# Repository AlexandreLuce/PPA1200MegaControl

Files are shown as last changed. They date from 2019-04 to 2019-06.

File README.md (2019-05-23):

# PPA1200MegaControl
Hardware and Software based on arduino mega and Nextion lcd touchscreen designed to replace defective Stage Accompany PPA 1200 Front Panel

## This is a Work In Progress !!

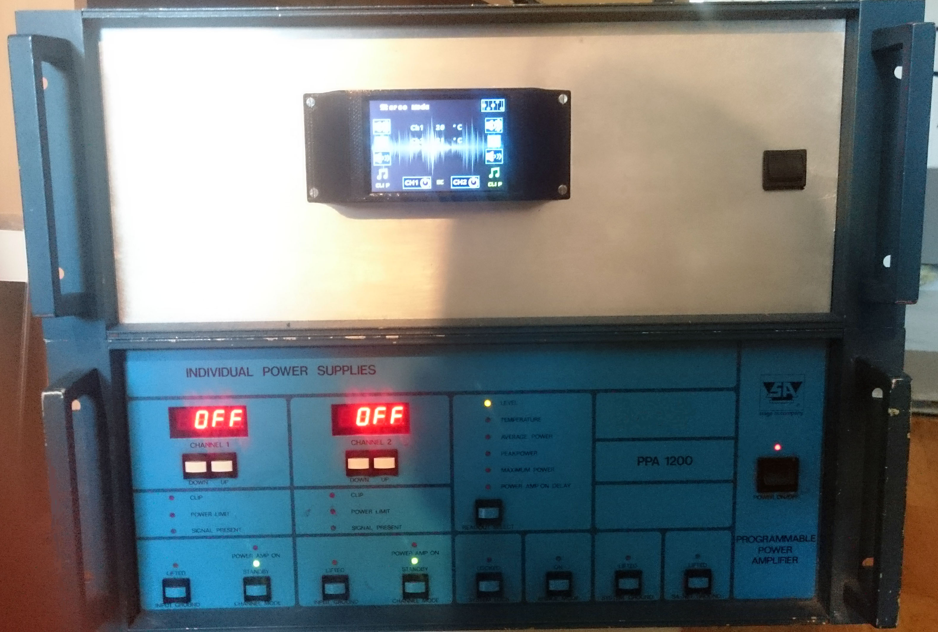
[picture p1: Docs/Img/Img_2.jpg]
Before / After
   

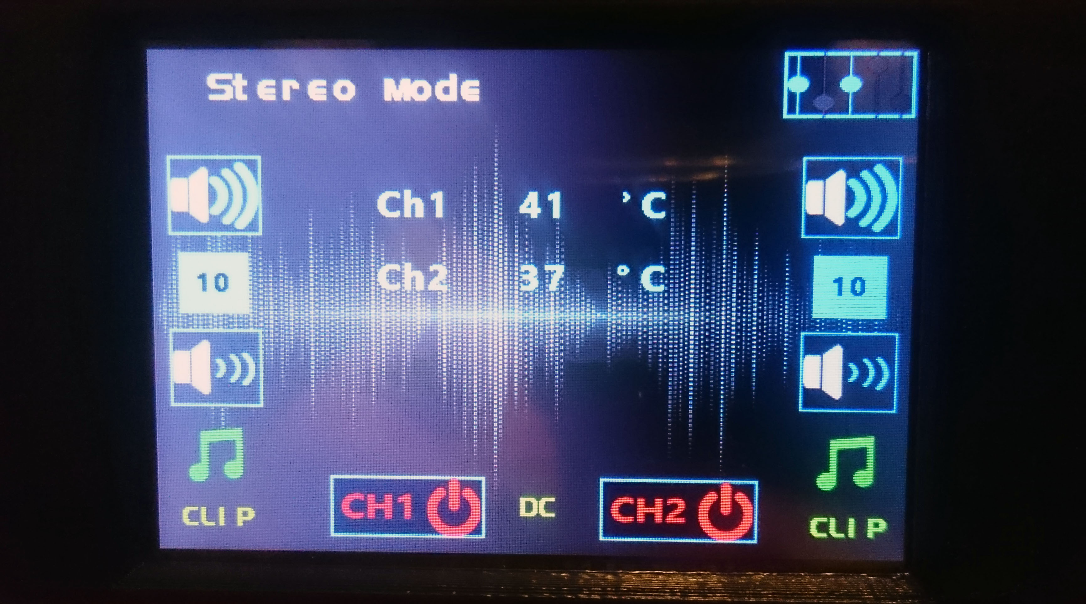
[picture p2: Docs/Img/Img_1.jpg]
Screen


<h2>To Do</h2> 

  - [X] Power off on DC fail function
  - [X] Limit Fan threshold
  - [X] Delay for channel start
  - [X] Test clip feedback
  - [ ] Implement fast ADC
  - [ ] Implement fast digital write
  - [ ] Improve volume function in bridge mode (sync com with AD7545)
  - [X] Fix volume function => Start/Steps
  - [ ] Record Uptime
  - [X] Auto Start Function
  - [X] Arduino feedback to lcd for Lift Chassis, Volume Synchronisation
  - [X] Arduino feedback to lcd for Lift Input and Filter Channels 1 2
  - [ ] Improve 3d part with a sliding cover, and better lcd panel fixing 
  - [X] Find analog input voltage to peak and rms volts conversion
  - [X] Display peak power and rms power
  - [X] Volume reduction function regarding power
  - [X] Volume reduction function in case of clip
  - [ ] Add remote control with RS232 Serial TTL to TCP/ IP RJ45 Convert Transmission Module

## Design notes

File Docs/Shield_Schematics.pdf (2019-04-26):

Vin
+5V | Bus 0 ========= | 1 | 26 | =========Bus 1
GND | Bus 2 ========= | 2 | 25 | =========Bus 3
A0 ================ | Bus 4 ========= | 3 | 24 | =========Bus 5
A1 ================ | Bus 6 ========= | 4 | 23 | =========Bus 7
A2 ================== | Bus 8 ========= | 5 | 22 | =========Bus 9
A3======================= | Bus 10 ========= | 6 | 21 | =========Bus 11
A4==================== | | 7 | 20 | =========RMS V
A5 ================== | Supply Lvl ========= | 8 | 19 | =========RMS I
A6 ================= | CS_AD7545 ========= | 9 | 18 | =========Signal
A7 ================== | Temp ========= | 10 | 17 | =========DC
A8 =================== | Clip ========= | 11 | 16 | =========Peak V
A9 =================== | Main GND ========= | 12 | 15 | =========-18V
A10 ================= | Peak I ========= | 13 | 14 | =========+18V
A11=================
A12===================
A13===================
A14==================
A15=================== | 1 | ========= CS_74HC373
D0 | RX0 ======== | 2 | ========= Gnd
D1 | TX0 | =======
D2 | PWM
D3 | PWM
D4 | PWM
D5 | PWM | | 1 | ========= +85V
D6 | PWM | | 2
D7 | PWM | | 3 | ========= -85V
D8 | PWM | | 4
D9 | PWM | | 5 | ========= +18V
D10 | PWM | | 6 | ========= -18V
D11 | PWM | | 7 | ========= Gnd Signal
D12 | PWM | | 8 | ========= Main GND
D13 | PWM | | 9 | ========= +5V
D14 | TX3 | | 10 | ========= Gnd
D15 | RX3 | | 11 | ========= Lift Chassis / Fan
D16 | TX2 | ====== | 12 | =========
D17 | RX2 | ====== | 13 | =========
D18 | TX1 | | 14 | ========= Power
D19 | RX1 | | 15 | ========= DDC+
D20 | SDA | | 16 | ========= DDC-
D21 | SCL
D22
D23 | ====== | 220Ω===
D24
D25 | ====== | 220Ω=== | 1 | ========= Signal-
D26 | | | 2 | ========= Signal+
D27 | ====== | 220Ω=== | 3 | ========= Gnd Signal
D28 | | | 4 | ========= Signal Bridge-
D29 ========220Ω=== | 5 | ========= Signal Bridge+
D30 | | | 6
D31 | ====== | 220Ω=== | 7
D32
D33 | ====== | 220Ω===
D34
D35=========220Ω===
D36 | | | 1 | ========= +5V
D37 ========220Ω=== | 2 | ========= +5V
D38 | | | 3 | ========= Main GND
D39 | =======220Ω=== | 4 | ========= Main GND
D40 | | | 5 | ========= CH1 CS_74HC373
D41 | ====== | 220Ω=== | 6 | ========= Main GND
D42 | | | 7 | ========= Main GND
D43 | ====== | 220Ω=== | 8 | ========= CH2 CS_74HC373
D44 | | | 9 | ========= Sanet
D45==========220Ω=== | 10 | ========= Sanet
D46 | | | 11 | ========= Sanet
D47=========220Ω=== | 12 | ========= Sanet
D48
D49=========220Ω=== CS_AD7545

### SA PPA1200 / Arduino Control Schematics

+12V
Relay

Pre-Amplifier Latch Connector

Pre-Amplifier Alim Connector

Pre-Amplifier Signal Connector

Supply Analog Digital

Arduino 2560

USB PC

# LCD Touch Channel 1 Channel 2

Supply Lvl
Signal
Temp

Signal

Clip

CS_AD7545 | Channel 1
| Channel 2
D50========= ========= | | | DC | Channel 1
D51=========220Ω=== CS_74HC373
D52========= ========= | | | DC | Channel 2
D53 | ====== | 220Ω=== CS_74HC373
Bus 0 | Ground Lift Input
Bus 1 | Bridge Mode
Bus 2 | Power
Bus 3 | Out Relay
Bus 4 | Gnd Lift Chassis / Fan
Bus 5 | Filter

Bus 6

RX
TX

Bus 10

Bus 11

Bus 8

Front Panel Connector

Bus 7

Channel 1 + Channel 2

Pre-Amplifier Data Connector

Temp
Clip
Peak I
RMS V
RMS I
Peak V

Peak I
RMS V
RMS I
Peak V
Supply Lvl

Bus 9

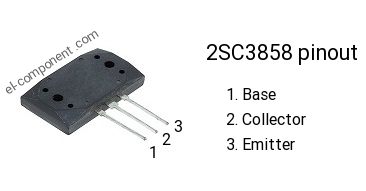
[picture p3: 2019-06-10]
Docs/Datasheets/2sc3858-pinout.jpg

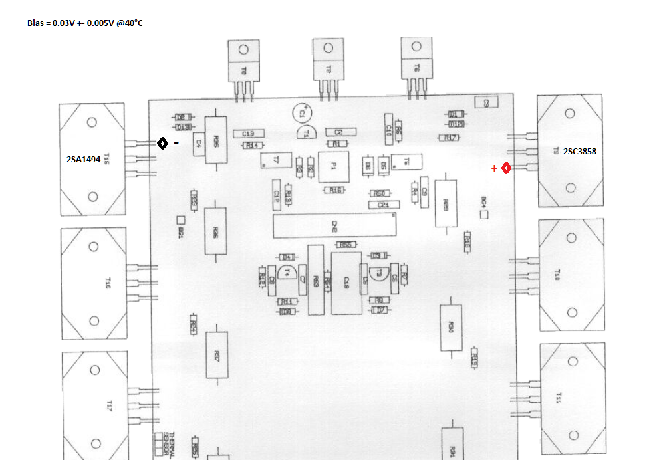
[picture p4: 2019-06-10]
Docs/Bias.png

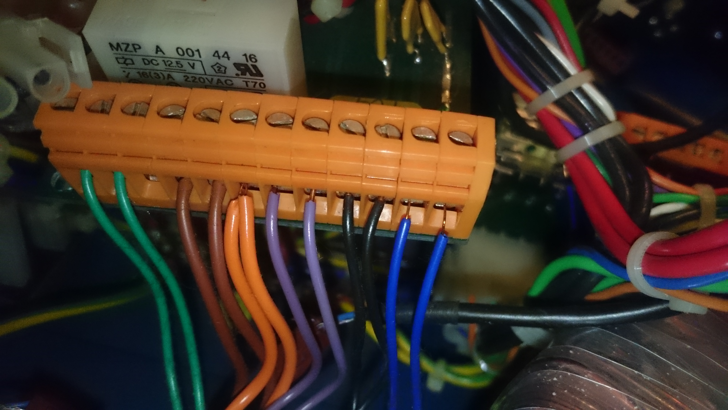
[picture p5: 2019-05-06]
Docs/MKII_RegSupply_Connections.JPG

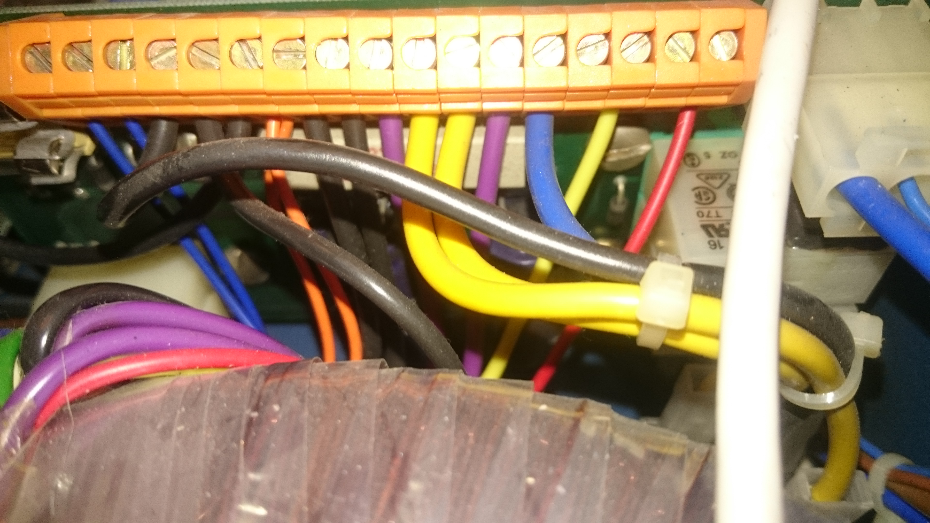
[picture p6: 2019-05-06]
Docs/MKII_Supply_Connections.JPG

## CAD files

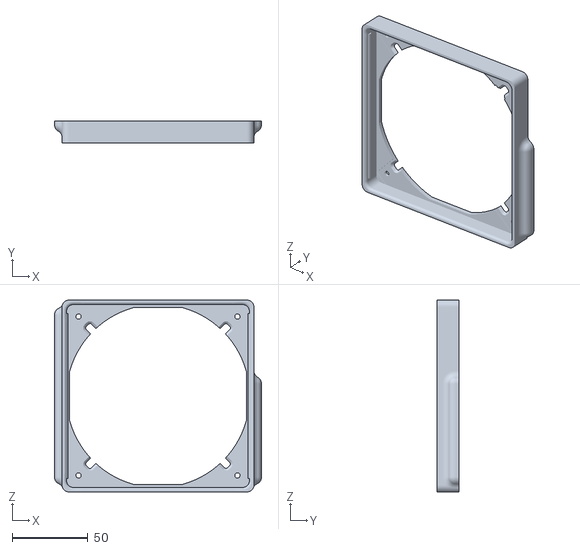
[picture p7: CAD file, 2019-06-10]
3D Parts/SA__Filter_part2.stl
136.6 x 14.3 x 126.6

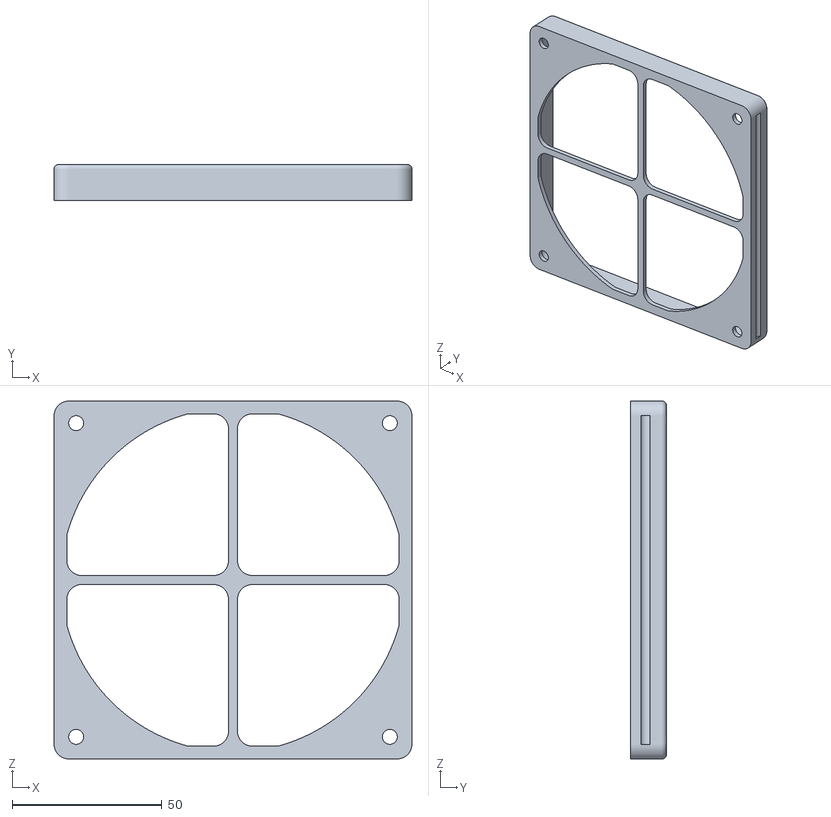
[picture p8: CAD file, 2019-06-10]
3D Parts/SA__Filter_part1.stl
119.6 x 12.0 x 119.6

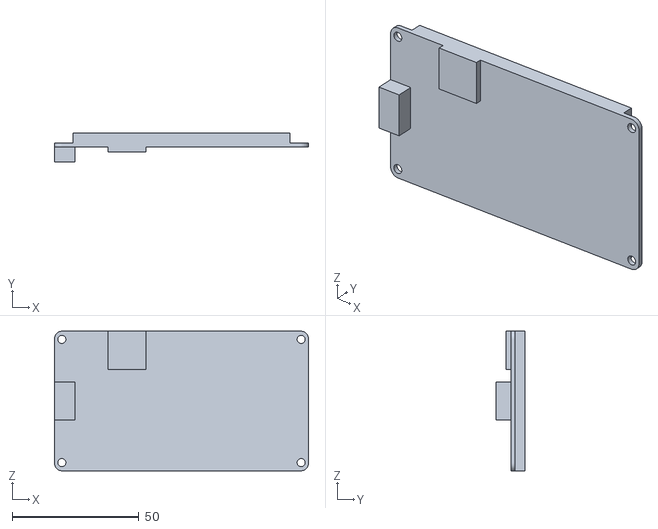
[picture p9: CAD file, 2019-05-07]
3D Parts/3.5-Display.STL
100.0 x 11.5 x 55.0

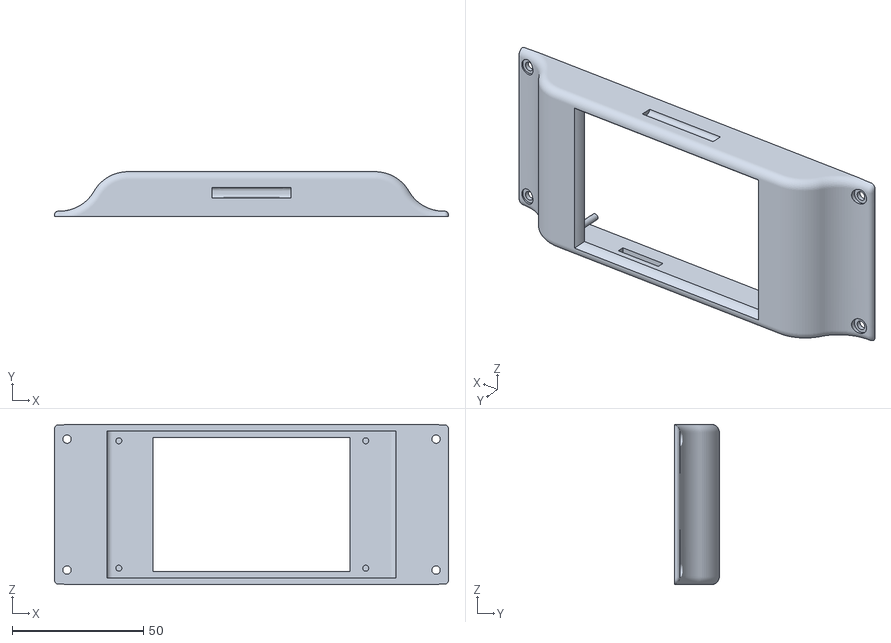
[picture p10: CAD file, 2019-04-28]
3D Parts/FrontPanelNextion_V1.stl
150.0 x 17.0 x 61.0

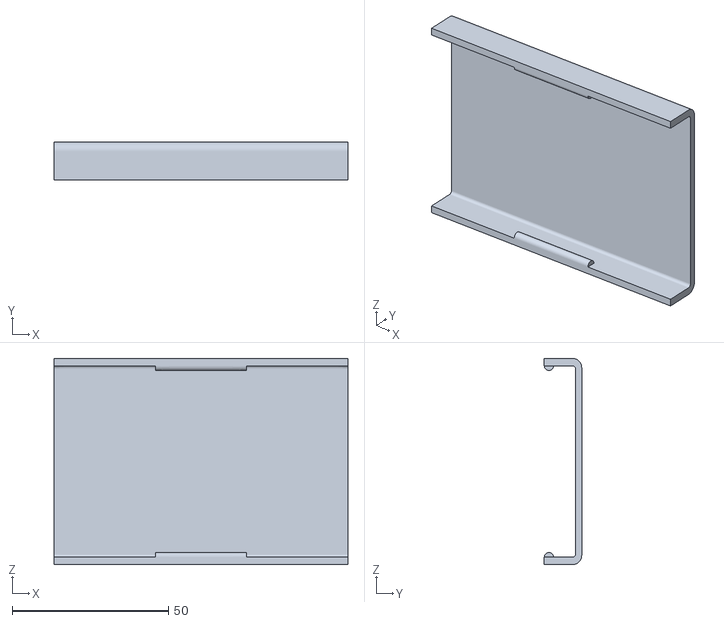
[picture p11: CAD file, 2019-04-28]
3D Parts/Cover_V1.stl
94.0 x 12.0 x 66.0

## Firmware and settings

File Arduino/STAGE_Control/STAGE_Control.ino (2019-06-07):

#include <EEPROM.h>
#include "Nextion.h"

/*******************************************************************
 * Pin configuration
 * 
 *******************************************************************/
//Declare Control Bus
const int buspins[12] = {25, 23, 29, 27, 33, 31, 37, 35, 41, 39, 45, 43}; // bus 0,1,2,3,4,5,6,7,8,9,10,11

const int CS_HC[2] = {51,53};    //Chip select 74HC373 Ch.1 Ch.2
const int CS_AD[2] = {49,47};   //Chip select AD7545 Ch.1 Ch.2

//Declare Datas Bus 
const byte ibuspins[2][9] = {
                             {A8, A9, A10, A11, A12, A13, A14, A15,52},
                             {A0, A1, A2, A3, A4, A5, A6, A7,50},
                            };

/*******************************************************************
 * Timers configuration
 * 
 *******************************************************************/

int unsigned timer1_lcdmsg = 10000;
int unsigned timer2_ProcTemp = 30000;
int unsigned timer3_ProcDC = 2;
int unsigned timer4_ProcSignal = 250;
int unsigned timer5_ProcClip = 20;
int unsigned timer6_ProcSupply = 100;
int unsigned timer7_ProcInfo = 250;
int unsigned timer8_ChPwr = 8000;
int unsigned timer9_ProcPwr = 30;
int unsigned disp_timer1_DC = 2000;


/*******************************************************************
 * Default EEPROM Values
 * 
 *******************************************************************/

int unsigned MaxVol[2] = {40,40};
int unsigned StartVol[2] = {0,0};
byte unsigned VolumeStep[2] = {1,1};
byte unsigned VolSyncState = 0;
byte unsigned CliftState = 0;
byte unsigned LiftState[2] = {0,0};
byte unsigned FilterState[2] = {0,0};
byte unsigned AutoStartState[2] = {0,0};
byte unsigned ClipLState[2] = {1,1};
byte unsigned PwLimitState[2] = {0,0};
int unsigned PwLimit[2] = {300,300};
byte unsigned bridgeState = 0;
int unsigned FanTemp = 30;

/*******************************************************************
 * Internal configuration
 * !!! NOTHING TO CONFIGURE !!! 
 *******************************************************************/
                                         
//Store AD/HC Bus
int HCbusvalue[2][12] ={ 
                       {0,0,0,0,0,0,0,0,0,0,0,0},
                       {0,0,0,0,0,0,0,0,0,0,0,0},
                       };
int ADbusvalue[2][12] ={
                       {0,0,0,0,0,0,0,0,0,0,0,0},
                       {0,0,0,0,0,0,0,0,0,0,0,0},
                       };

byte bitval;
int Volval[2] = {0,0};
byte unsigned FanState = 0;
byte unsigned PowerState[2] = {0,0};
byte unsigned setpin;
byte unsigned setAmp;
byte unsigned ADbus = 11;
byte unsigned ADpin = ADbus;
long unsigned int Cmillis;

//Store Info
int unsigned supply[2] = {0,0};
byte unsigned dc[2] = {0,0};
byte unsigned signl[2] = {0,0};
byte unsigned clip[2] = {0,0};
int unsigned rmsV[2] = {0,0};
int unsigned rmsI[2] = {0,0};
int unsigned rmsW[2] = {0,0};
int unsigned peakV[2] = {0,0};
int unsigned peakI[2] = {0,0};
int unsigned peakW[2] = {0,0};
int unsigned Temp[2] = {0,0};
int unsigned VolWanted[2] = {0,0};
byte unsigned OverPwr[2] = {0,0};
byte unsigned UnderPwr[2] = {0,0};
byte unsigned  CPage = 0;

long unsigned int LastMillis1 = 0;
long unsigned int LastMillis2 = 0;
long unsigned int LastMillis3 = 0;
long unsigned int LastMillis4 = 0;
long unsigned int LastMillis5 = 0;
long unsigned int LastMillis6 = 0;
long unsigned int LastMillis7 = 0;
long unsigned int LastMillis9 = 0;
long unsigned int LastPwr1Millis = 0;
long unsigned int LastPwr2Millis = 0;
long unsigned int disp_LastMillis1 = 0;

#include "InitAmp.h"

/*******************************************************
* 
* Setup
* 
*******************************************************/

void setup()
{
//Init Pins
//analogReference(DEFAULT);
for(int i=0; i<12; i=i+1) pinMode(buspins[i], OUTPUT);  
for(int i=0; i<2; i=i+1) pinMode(CS_HC[i], OUTPUT);
for(int i=0; i<2; i=i+1) pinMode(CS_AD[i], OUTPUT);

// INIT AD7545 //INIT 74HC373
digitalWrite(buspins[12], LOW);
digitalWrite(CS_HC[1], HIGH);
digitalWrite(CS_HC[0], HIGH);
digitalWrite(CS_AD[0], LOW);
digitalWrite(CS_AD[1], LOW);
delayMicroseconds(100);
digitalWrite(CS_HC[0], LOW);
digitalWrite(CS_HC[1], LOW);
digitalWrite(CS_AD[0], HIGH);    
digitalWrite(CS_AD[1], HIGH);
sendHC(4,1);
FanState = 1;
//Init Serial 1
//Serial.begin(115200);
//Init EEPROM
initEEprom();
//Init Bus
InitStates();
//Init Amp
InitAmp(0);
InitAmp(1);
//Init Lcd
InitLcd();
AutoStart();
}

/*******************************************************
* 
* Loop
* 
*******************************************************/
void loop(){
  
nexLoop(nex_listen_list);
ProcessDatas();
              
}

/*******************************************************
* End of File 
*******************************************************/

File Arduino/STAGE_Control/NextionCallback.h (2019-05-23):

/**********************************************
 * 
 * 
 * Fonction callback appelée lorsque l'on appuie sur le 
 * bouton sur la tablette Nextion.
 * 
 * 
 *********************************************/


/**************************************
 * 
 * Page : Home Stereo
 * 
 **************************************/

/**************************************
 * Power Channel 1
 **************************************/
void Pch1PopCallback()
{
    if(supply[0] < 800 && PowerState[0] == 0 && dc[0] == 1 && millis() - LastPwr1Millis > timer8_ChPwr)
    {
    sendHC(2,0);  //Power
    delay(400);
    sendHC(3,0);  // Out
    Ch1Pwr.setValue(1);
    PowerState[0] = 1;
    msg.setText("Ch1 ON");
    LastMillis1=millis();
    VolumeStart(0);
    Vol1.setValue(Volval[0]);
    }
    else if(supply[0] < 800 && PowerState[0] == 0 && dc[0] == 1 && millis() - LastPwr1Millis < timer8_ChPwr) 
    {
      msg.setText("Wait for Ch1 ON");
      LastMillis1=millis();
    }
    else if (supply[0]>800 && PowerState[0] == 1)
    {
    VolumeStop(0);
    Vol1.setValue(Volval[0]);
    sendHC(3,0);  // Out
    delay(100);
    sendHC(2,0);  // Power
    Ch1Pwr.setValue(0);
    PowerState[0] = 0;
    msg.setText("Ch1 OFF");
    LastMillis1=millis();
    }
}

/**************************************
 * Volume Up Channel 1
 **************************************/
 void Vplus1PopCallback(void *ptr)
{   
    Volume(HIGH,0);      
    Vol1.setValue(Volval[0]);
    VolWanted[0] = Volval[0];
    if(VolSyncState == 1){
      Volume(HIGH,1);      
      Vol2.setValue(Volval[1]);
      VolWanted[1] = Volval[1];
      }    
}

/**************************************
 * Volume Down Channel 1
 **************************************/
void Vmin1PopCallback(void *ptr)
{
    Volume(LOW,0);    
    Vol1.setValue(Volval[0]);
    VolWanted[0] = Volval[0];
    if(VolSyncState == 1){
      Volume(LOW,1);      
      Vol2.setValue(Volval[1]);
      VolWanted[1] = Volval[1];
      }   
}

/**************************************
 * Power Channel 2
 **************************************/
void Pch2PopCallback()
{
    
    if(supply[1]<800 && PowerState[1] == 0 && dc[1] == 1 && millis() - LastPwr2Millis > timer8_ChPwr) 
    {
    sendHC(2,1);  //Power
    delay(400);
    sendHC(3,1);  // Out
    Ch2Pwr.setValue(1);
    PowerState[1] = 1;
    msg.setText("Ch2 ON");
    LastMillis1=millis();
    VolumeStart(1);
    Vol2.setValue(Volval[1]);
    }
    else if(supply[1]<800 && PowerState[1] == 0 && dc[1] == 1 && millis() - LastPwr2Millis < timer8_ChPwr) 
    {
      msg.setText("Wait for Ch2 ON");
      LastMillis1=millis();
    }
    
    else if (supply[1]>800 && PowerState[1] == 1)
    {
    VolumeStop(1);
    Vol2.setValue(Volval[1]);
    sendHC(3,1);  // Out
    delay(100);
    sendHC(2,1);  // Power
    Ch2Pwr.setValue(0);
    PowerState[1] = 0;
    msg.setText("Ch2 OFF");
    LastMillis1=millis();
    }
}

/**************************************
 * Volume Up Channel 2
 **************************************/
void Vplus2PopCallback()
{
    Volume(HIGH,1);      
    VolWanted[1] = Volval[1];
    Vol2.setValue(Volval[1]);  
    if(VolSyncState == 1){
      Volume(HIGH,0);
      VolWanted[0] = Volval[0];      
      Vol1.setValue(Volval[0]);
      }   
}

/**************************************
 * Volume Down Channel 2
 **************************************/
void Vmin2PopCallback()
{
    Volume(LOW,1);    
    VolWanted[1] = Volval[1];
    Vol2.setValue(Volval[1]);
    if(VolSyncState == 1){
      Volume(LOW,0);
      VolWanted[0] = Volval[0];      
      Vol1.setValue(Volval[0]);
      }     
}

/**************************************
 * 
 * Page : Home Bridge
 * 
 **************************************/

/**************************************
 * Power Channels
 **************************************/
void PowerPopCallback()
{
  if(supply[0]<800 && PowerState[0] == 0 && dc[0] == 1 && millis() - LastPwr1Millis > timer8_ChPwr && supply[1]<800 && PowerState[1] == 0 && dc[1] == 1 && millis() - LastPwr2Millis > timer8_ChPwr)
    {
    sendHC(2,0);  //Power 1
    delay(400);
    sendHC(2,1);  //Power 2
    delay(400);
    sendHC(3,0);  // Out 1
    sendHC(3,1);  // Out 2
    PowerBR.setValue(1);
    LastPwr1Millis=millis();
    LastPwr2Millis=millis();
    PowerState[0] = 1;
    PowerState[1] = 1;
    msg.setText("Power ON");
    LastMillis1=millis();
    StartVol[1] = StartVol[0];
    VolumeStart(0);
    VolumeStart(1);
    Vol.setValue(Volval[0]);
    }
    else if(supply[0]<800 && PowerState[0] == 0 && dc[0] == 1 && millis() - LastPwr1Millis < timer8_ChPwr || supply[1]<800 && PowerState[1] == 0 && dc[1] == 1 && millis() - LastPwr2Millis < timer8_ChPwr) 
    {
      msg.setText("Wait for Power");
      LastMillis1=millis();
    }
    else if (supply[0]>800 && PowerState[0] == 1 && supply[1]>800 && PowerState[1] == 1)
    {
    VolumeStop(0);
    Vol.setValue(Volval[0]);
    sendHC(2,0);  // Out 1
    sendHC(2,1);  // Out 2
    delay(200);
    sendHC(3,0);  // Power 1
    sendHC(3,1);  // Power 2
    PowerBR.setValue(0);
    PowerState[0] = 0;
    PowerState[1] = 0;
    msg.setText("Power OFF");
    LastMillis1=millis();
    }
}

/**************************************
 * Volume Up
 **************************************/
void VplusPopCallback(){
Volume(HIGH,0);
Volume(HIGH,1);
Vol.setValue(Volval[0]);
}


/**************************************
 * Volume Down
 **************************************/
void VminPopCallback()
{
Volume(LOW,0);
Volume(LOW,1);
Vol.setValue(Volval[0]);
}

/************************************
 * 
 * Page : Common Settings
 * 
*************************************/

/**************************************
 * Chassis Lift activation
 **************************************/
void SelectCliftPopCallback()
{

    if(CliftState == 0) 
    {
    sendHC(4,0);
    Clift.setValue(1);
    Clift.setText("Chassis Lift Active");
    CliftState = 1;
    }
    else if(CliftState == 1) 
    {
    sendHC(4,0);
    Clift.setValue(0);
    Clift.setText("Chassis Lift Inactive");
    CliftState = 0;
    }
}
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

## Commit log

2019-04-28 Add 3d parts
    V1 parts WIP
    [Cover_V1.stl, FrontPanelNextion_V1.stl]
2019-05-01 improve DC / Power function
2019-05-02 vol on/off regarding power
2019-05-03 Change timers
2019-05-21 Power and Clip Limiter
2019-05-22 Power Limit Switch
2019-06-10 Add 3d parts for filter addon
    [SA__Filter_part1.stl, SA__Filter_part2.stl]
